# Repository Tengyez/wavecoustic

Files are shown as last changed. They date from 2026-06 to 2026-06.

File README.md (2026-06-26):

# Wavecoustic

An ESP-32 with INMP441 mic to analyse piano sound using FFT (Fast Fourier transform) to light up WS2812B led on the corresponding across the piano key.

## Description

This is a controller for a LED strip that lights up a piano key when pressed. I know a version of this had been done before; however, as far as I know, there had only been a version where the input for the LED was from MIDI, which is impossible to do with an older piano or an acoustic piano. I wanted to make this project so much because looking back I would have practiced the piano so much more if it wasn't so boring. So, my goal is to use an actual microphone input and FFT to translate the sound wave signal into individual key notes. So that it becomes fun and usable. I wanted to make this project because I have an acoustic piano but I can't use led on it because it doesn't have a midi output so this project that only use sound will be a game changer for me! Thank you!

## Getting Started

### Usage

* Place the 1.4m led strip over the piano in possition.
* Charge your external LIPO-battery using Tp4056 usb-c charging module.
* Plug the external lipo battery in and rest it on the holder (please be aware of the polarlity).
* Set the setting mode and brightness via esp32-accesspoint captive portal.

### Assembling

* Print out the 3d parts (body,slider,topper,boostcover and please use the 3mf file I beg you)
* Put the esp-32 into the main body
* Stack the esp32 cover lid over the esp32 to lock it in place
* stick all the pin header into it own slot
* follow the wiring guide below
* put the microphone into the 6 headerpin slot
* stuff all the wiring jumper wires into the case
* connect the led strip into the external headerpin
* charge the lipo with the Tp4056 module (not include in the circuit and the case)
* connect the lipo to the external header pin
* cut your 2m led strip to your piano size
* use a multimeter to check the boost converter and adjust first using a screw prior to adding it to the circuit
* take the sliding lid and close it
* mount the led and the component box on your piano
* The only point require soldering are the INMP441 mic and the GND wires. 

### Wiring
* INMP441 - ESP32
* VDD  - 3.3V
* GND  - GND
* SCK  - GPIO32
* WS   - GPIO25
* SD   - GPIO34
* L/R  - GND
* WS2812B LED STRIP
* DIN  - 300Ω → GPIO13
* GND  - GND
* MT3608 boost converter (use a multimeter to check the boost and adjust first prior to adding electricity)
* +Vout - led strip 5v pin
* -Vout - GND
* Lipo battery (preferably 20 000mah)
* Splice the red wire before connecting it to the boost converter and connect it to ESP-32 VIN pin
* Red wire   - MT3608 +Vin pin
* Black wire - GND
* Splice all GND together and add solder and a electrical tape!!!
* Refers to the schematic down below for more indepth guide.

### Firmware

* The code is in C++ made for ESP-32
* The library version might change over time, please recheck it again.
* Sidenote: I'm not really sure about the code but I tried my best to polish it because my friend quit half way :(
* Check out the [Firmware](firmware/Firmware.ino)
## Materials

This is the BOM of the entire project, just buy the normal one not the pcb version and just use jumper wire with minimal soldering required except for slicing GND together.
```
ESP-32 devkit v1           1 pcs. 8usd
INMP441 mic                1 pcs. 1usd
WS2812B led                2m 144/m 20usd
LIPO-battery               1 (reccomend atleast 10 000mah) 7usd
Tp4056 usb-c               1 (does not include in the build, only use the charge lipo externally) 1usd
MT3608 boost converter     1 pcs. 1usd
Female Jumper wires        30 pcs. 1usd
Male Jumper wires          15 pcs. 50cent
Pin headers                5 pcs. 25cent
Electrical tape            1 roll -
PLA 3d printing/time       ≈15g ≈45min -
Total: 39.75 usd
```

## Assembled Pictures


## Rendered Pictures


## Captive Portal interface


## Wiring Diagram 
SCH_Schematic1_2026-06-14 (1)_page-0001

# Zine Poster
waaavecoustic (1)

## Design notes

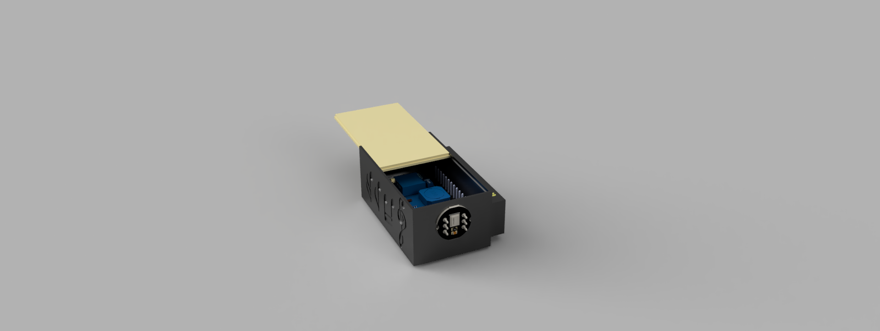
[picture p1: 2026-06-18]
docs/model_pictures/bottom_open.png

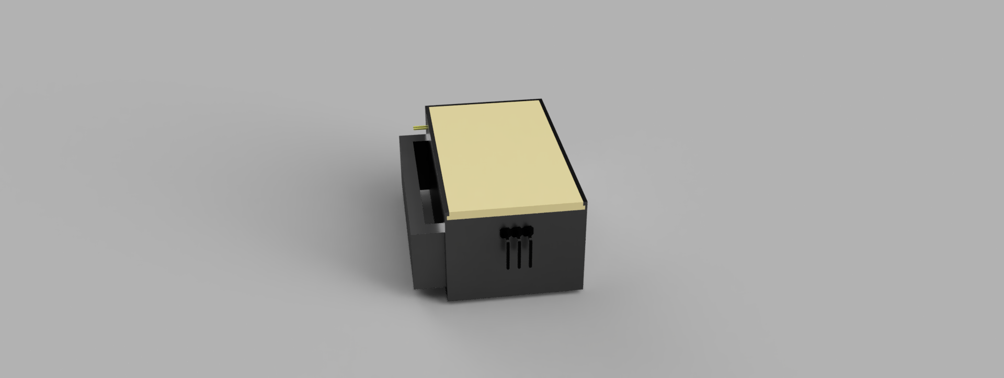
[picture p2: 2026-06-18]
docs/model_pictures/bottom_closed.png

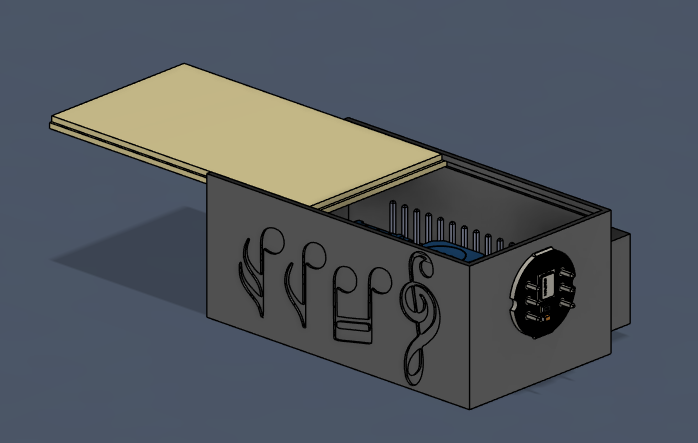
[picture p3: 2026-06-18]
docs/model_pictures/side_open.png

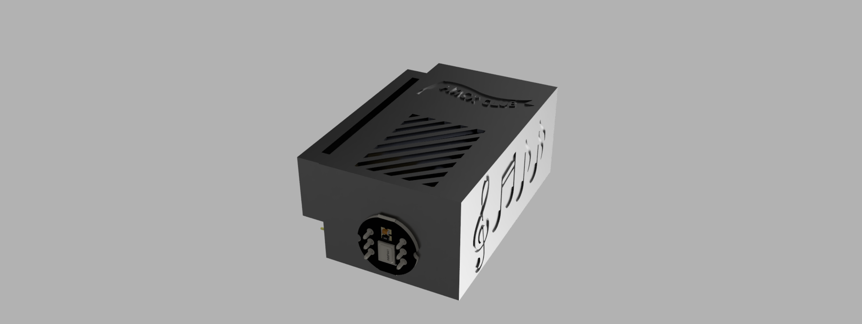
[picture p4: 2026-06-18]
docs/model_pictures/mainshot.PNG

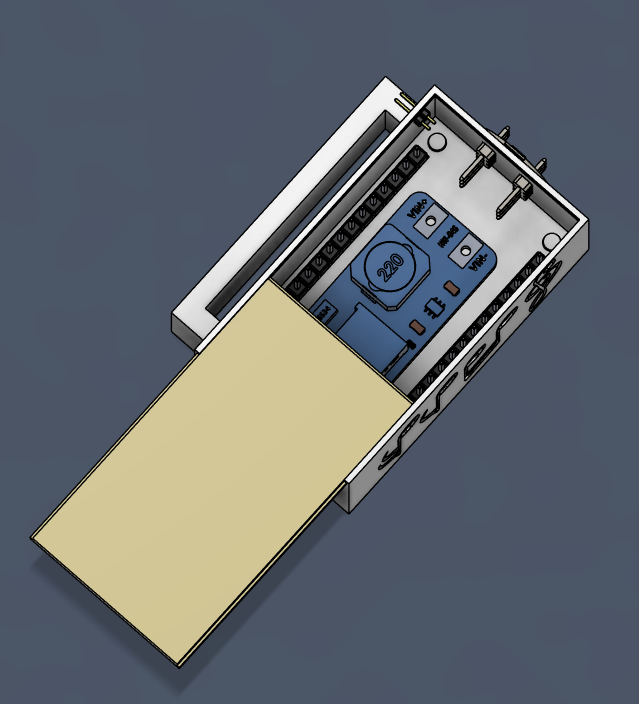
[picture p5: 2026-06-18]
docs/model_pictures/bottom_unrendered.png

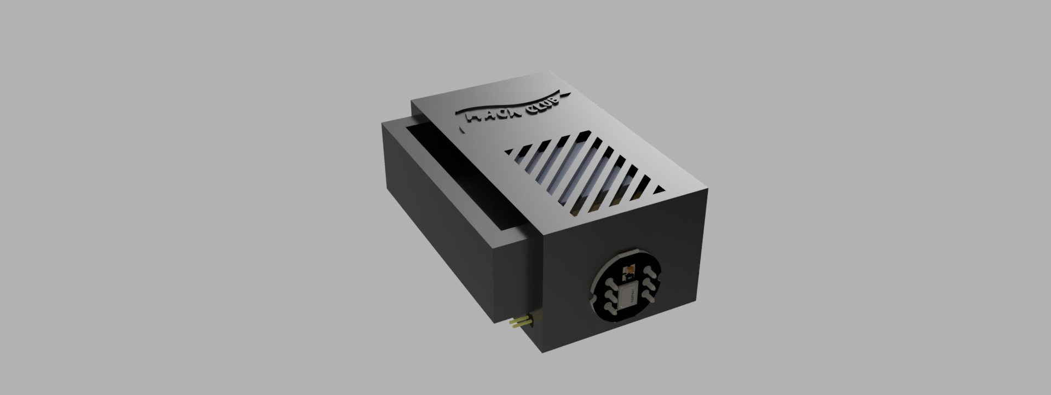
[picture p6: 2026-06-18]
docs/model_pictures/left_front.png

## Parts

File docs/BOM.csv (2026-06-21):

component | quantity | comment | link | cost
ESP-32 devkit v1 | 1pcs. | - | https://shopee.co.th/ESP32-DOIT-ESP32-DEVKIT-V1-ESP-32S-NodeMCU-ESP-WROOM-32-Wi-Fi-and-Bluetooth-Dual-Core-ESP-32-ESP-32S-ESP-32D-i.56846818.6732213287 | 8usd
INMP441 mic | 1pcs. | - | https://www.allnewstep.com/product/4864/inmp441-%E0%B9%82%E0%B8%A1%E0%B8%94%E0%B8%B9%E0%B8%A5%E0%B9%84%E0%B8%A1%E0%B9%82%E0%B8%84%E0%B8%A3%E0%B9%82%E0%B8%9F%E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 | 1usd
LIPO battery | 1pcs. | reccomended 20 000mah | https://shopee.co.th/%E0%B9%81%E0%B8%9A%E0%B8%95%E0%B9%80%E0%B8%95%E0%B8%AD%E0%B8%A3%E0%B8%B5%E0%B9%88-3.7v-20000mAh-size1260110-li-polymer-%E0%B8%A5%E0%B8%B4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 | 7usd
WS2812B led | 2m | 144/m | https://shopee.co.th/Ws2812b-WS2812-Led-Strip-%E0%B8%AA%E0%B9%88%E0%B8%A7%E0%B8%99%E0%B8%9A%E0%B8%B8%E0%B8%84%E0%B8%84%E0%B8%A5%E0%B8%97%E0%B8%B5%E0%B9%88%E0%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 | 20usd
TP4056 | 1pcs. | not include in build (charge lipo externally) | https://www.ortech-online.com/product/434/1%E0%B8%8A%E0%B8%B4%E0%B9%89%E0%B8%99-aa477-%E0%B9%82%E0%B8%A1%E0%B8%94%E0%B8%B9%E0%B8%A5%E0%B8%8A%E0%B8%B2%E0%B8%A3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 | 1usd
MT3608 | 1pcs. | - | https://www.ortech-online.com/product/199/3%E0%B8%8A%E0%B8%B4%E0%B9%89%E0%B8%99-aa180-%E0%B9%82%E0%B8%A1%E0%B8%94%E0%B8%B9%E0%B8%A5%E0%B9%80%E0%B8%9E%E0%B8%B4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 | 1usd
Female Jumper | 30pcs. | gpio | https://www.ortech-online.com/product/344/1%E0%B8%8A%E0%B8%B4%E0%B9%89%E0%B8%99-aa047-%E0%B8%AA%E0%B8%B2%E0%B8%A2%E0%B9%80%E0%B8%8A%E0%B8%B7%E0%B9%88%E0%B8%AD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 | 1usd
Male Jumper | 15pcs. | gpio | https://www.ortech-online.com/product/344/1%E0%B8%8A%E0%B8%B4%E0%B9%89%E0%B8%99-aa047-%E0%B8%AA%E0%B8%B2%E0%B8%A2%E0%B9%80%E0%B8%8A%E0%B8%B7%E0%B9%88%E0%B8%AD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 | 50cent
Pin header | 5pcs. | 2.54mm | https://www.ortech-online.com/product/917/10%E0%B8%8A%E0%B8%B4%E0%B9%89%E0%B8%99-%E0%B8%81%E0%B9%89%E0%B8%B2%E0%B8%87%E0%B8%9B%E0%B8%A5%E0%B8%B2-%E0%B8%95%E0%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 | 25cent
Electrical tape | 1pcs. | a roll for covering copper wires | any | -
PLA | 15g | 45min | any | -
total cost: | 39.75usd

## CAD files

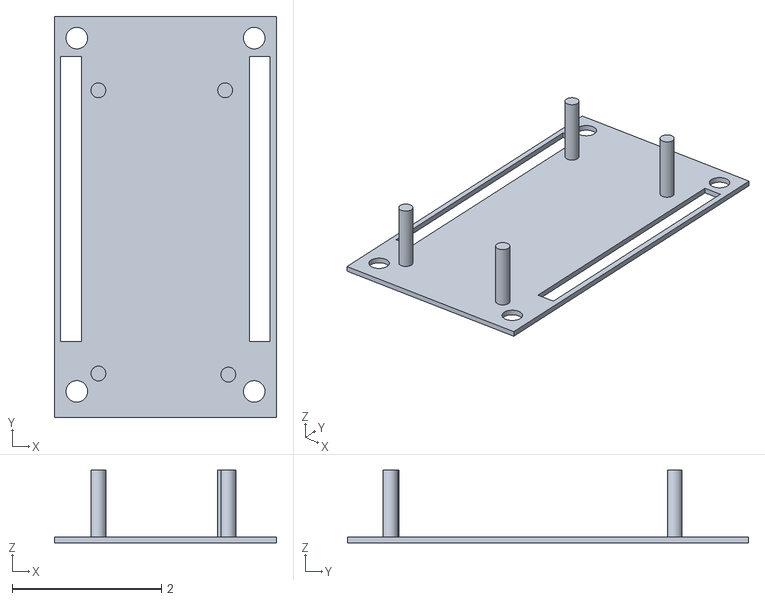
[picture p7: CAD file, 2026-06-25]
3d_print/reworked espcover.stl
2.98 x 5.38 x 0.975

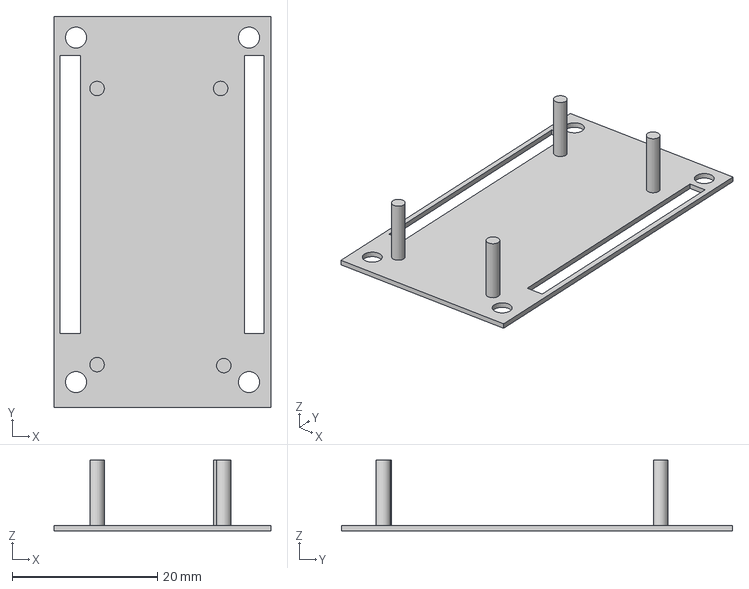
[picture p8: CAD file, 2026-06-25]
3d_print/esp32 cover rework fixing.3mf
29.8 x 53.8 x 9.75 mm

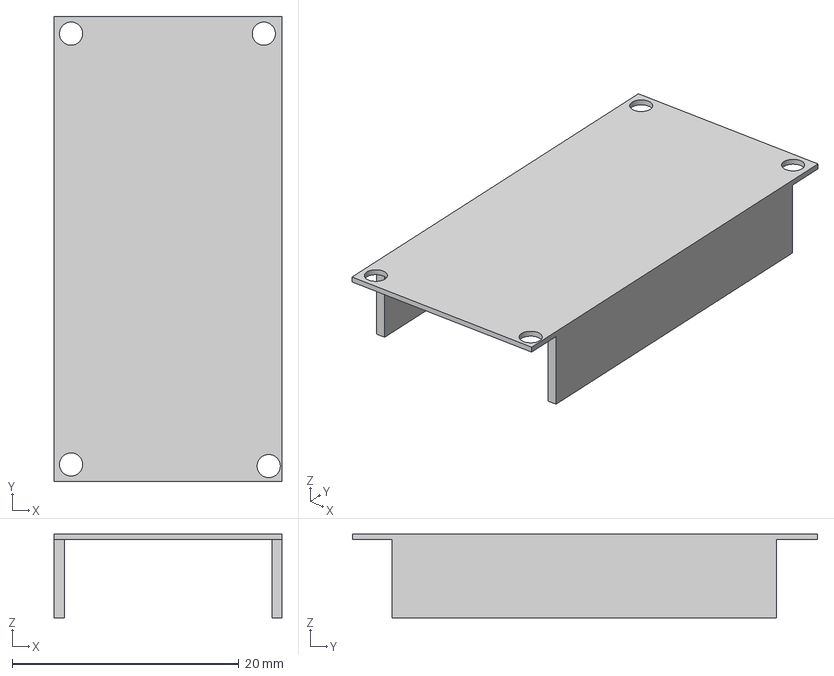
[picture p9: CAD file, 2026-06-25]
3d_print/boostcover.3mf
20.1 x 41.0 x 7.40 mm

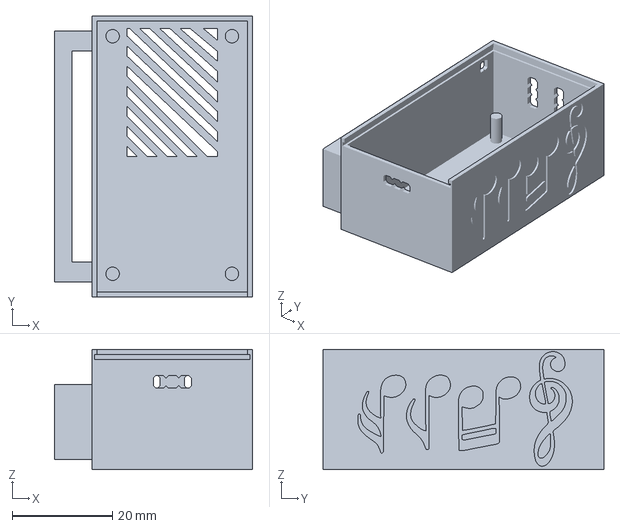
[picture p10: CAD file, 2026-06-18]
3d_print/body.3mf
39.5 x 56.0 x 24.0 mm

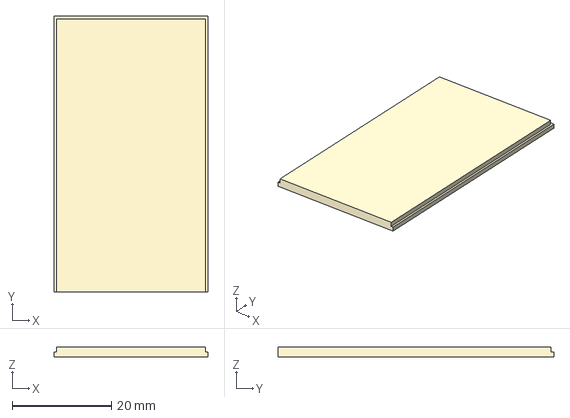
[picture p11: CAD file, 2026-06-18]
3d_print/slider.3mf
31.0 x 55.5 x 1.98 mm

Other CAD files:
3d_print/body.stl
3d_print/boostcover.stl
3d_print/slider.stl

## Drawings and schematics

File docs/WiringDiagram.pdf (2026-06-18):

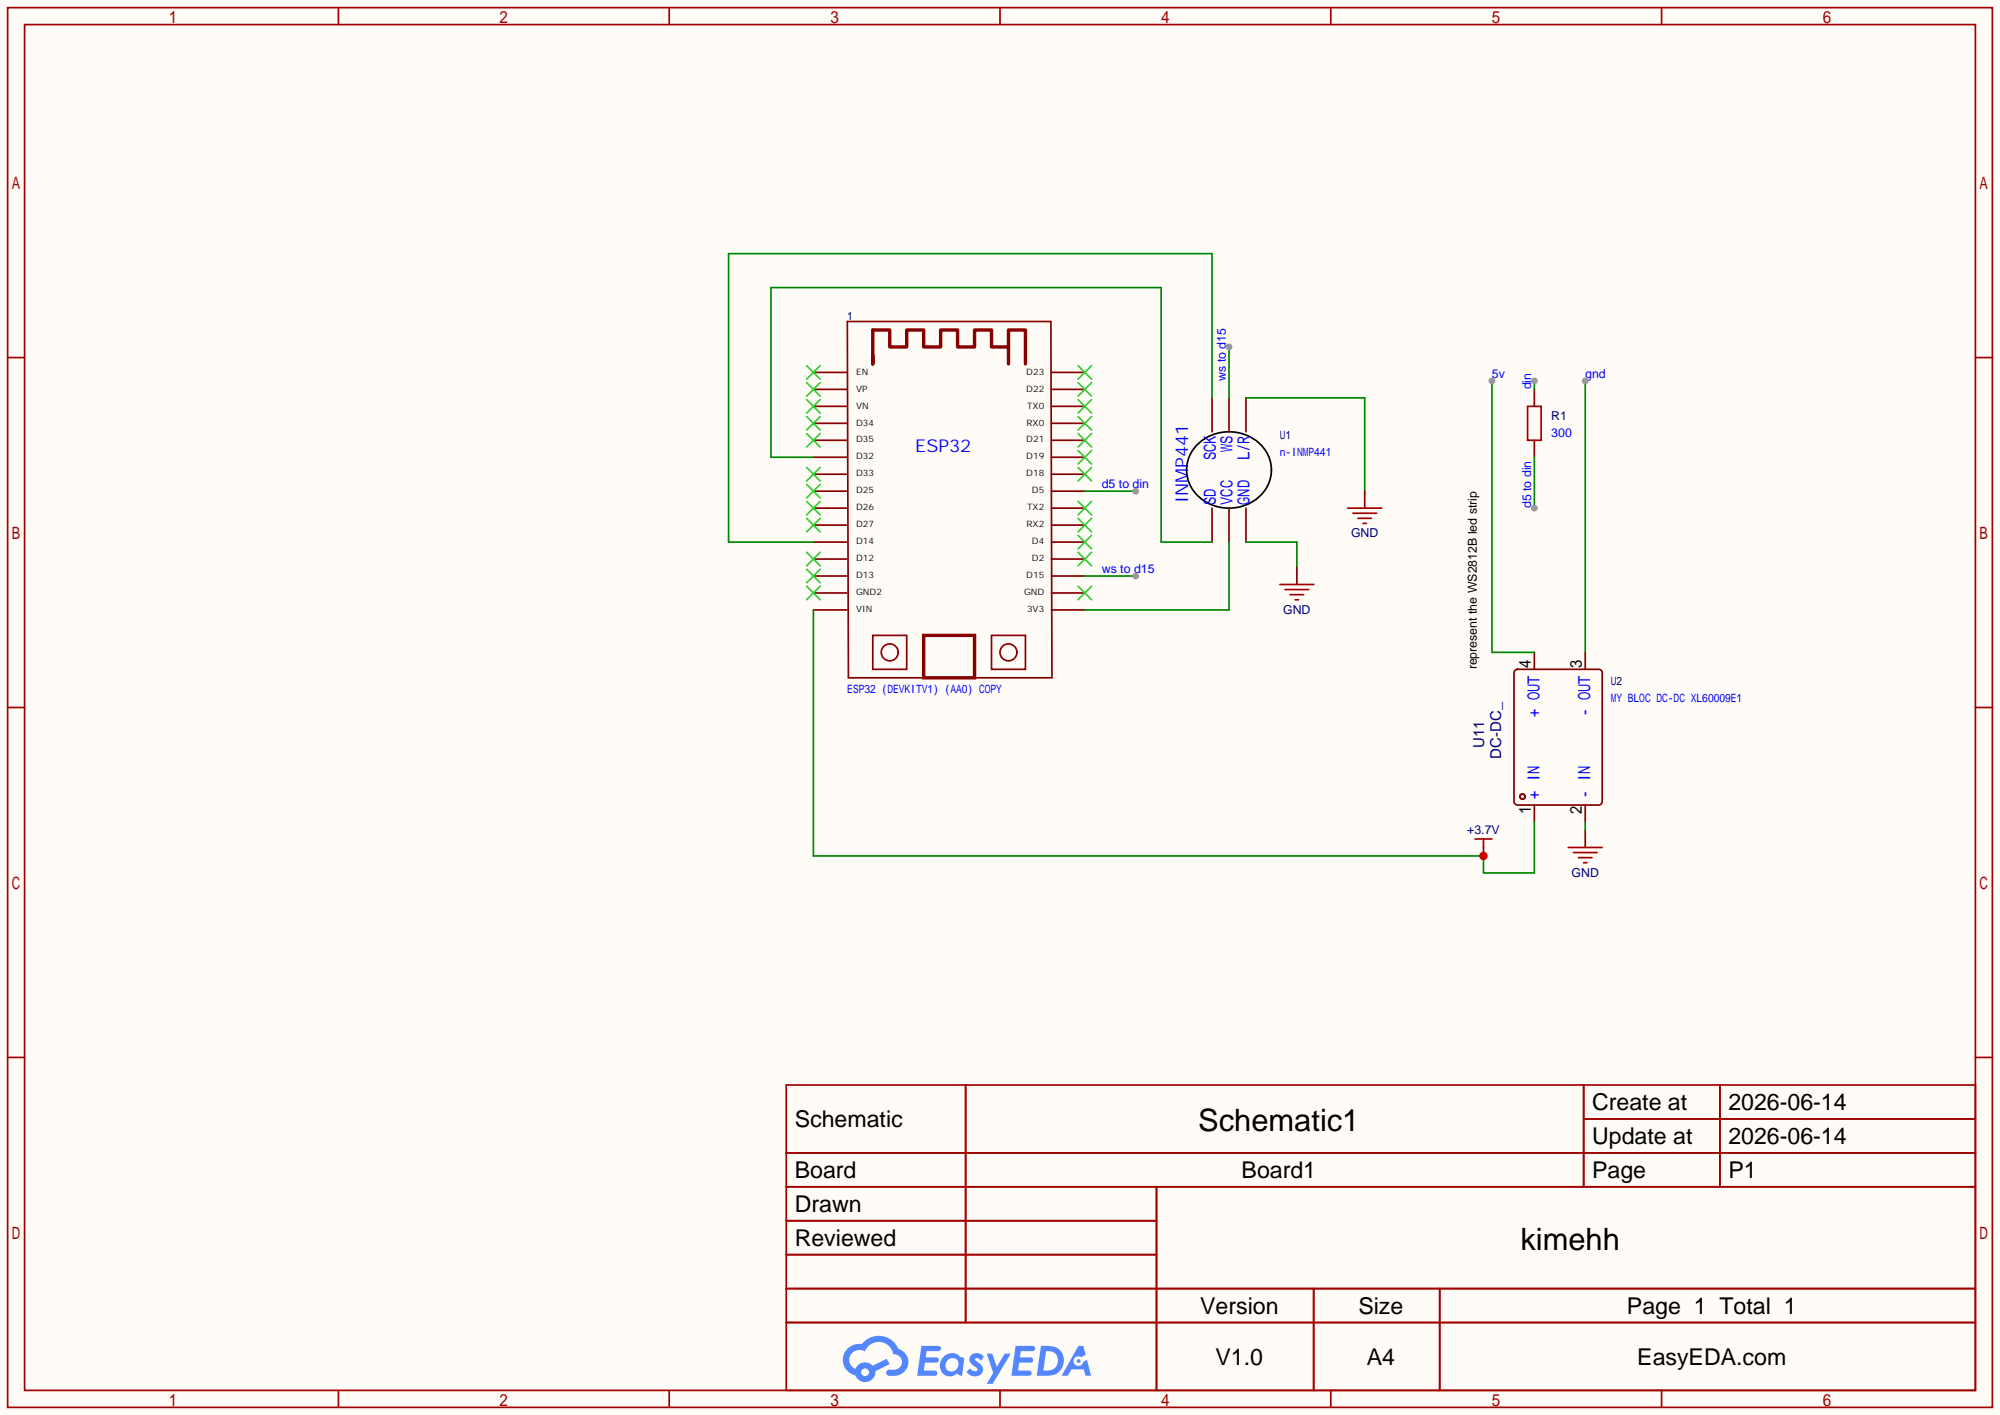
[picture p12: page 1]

represent the WS2812B led strip

MY BLOC DC-DC XL60009E1

Schematic | Schematic1 | Create at | 2026-06-14

Update at | 2026-06-14

Board | Board1 | Page | P1
Drawn | | kimehh
Reviewed

Version | Size | Page 1 Total 1
V1.0 | A4 | EasyEDA.com

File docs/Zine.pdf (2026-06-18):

## WAVE-COUSTIC

## by Teng & Kim 15y

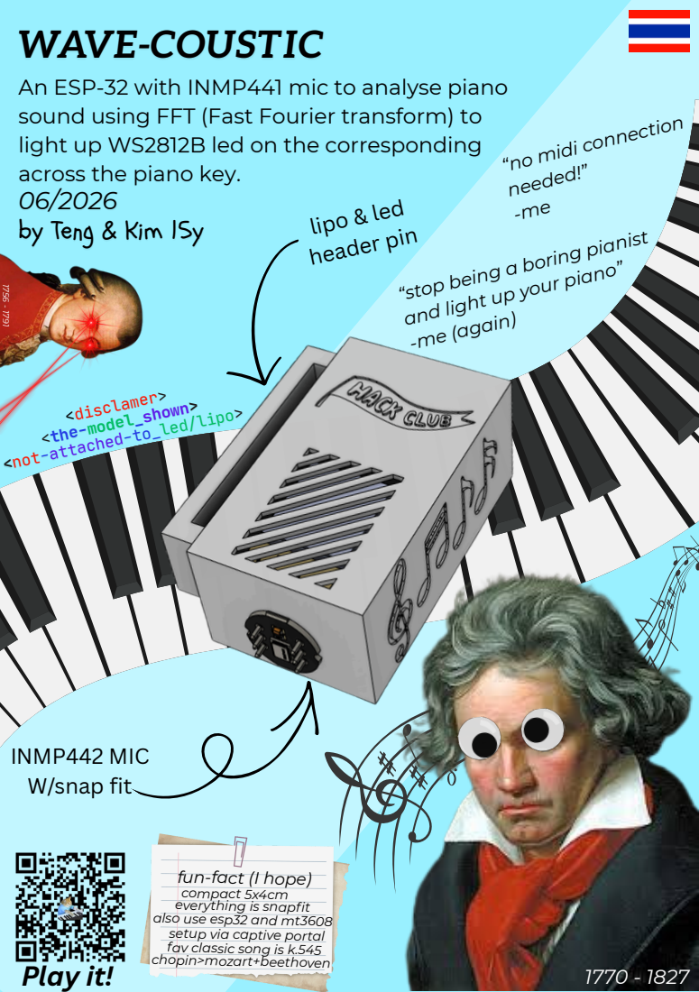
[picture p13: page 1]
needed!” -me; <disclamer> <the-model_; shown>; <not-at; s hed-to_; led/lipo>; clamer> <the-model_; shown> <not-attached-to_; Play it!; INMP442 MIC; W/snap fit; lipo & led header pin; compact 5x4cm; -me (again)

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

“no midi connection

“stop being a boring pianist

and light up your piano”

fun-fact (I hope)

everything is snapfit

also use esp32 and mt3608

setup via captive portal

fav classic song is k.545

chopin>mozart+beethoven

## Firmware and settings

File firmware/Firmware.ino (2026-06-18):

#include <Arduino.h>
#include <driver/i2s.h>
#include <arduinoFFT.h>
#include <FastLED.h>
#include <WiFi.h>
#include <ESPAsyncWebServer.h>
#include <AsyncWebSocket.h>
#include <DNSServer.h>

#define FREQ_MAX        4186.0f
#define FREQ_MIN        27.5f
#define SAMPLE          1024
#define SAMPLE_RATE     22050
#define MAG_THRESHOLD   3000

#define I2S_WS          25
#define I2S_SD          34
#define I2S_SCK         32
#define LED_PIN         13
#define JAX_ADC_PIN     35

#define NUM_KEY         88
#define LED_PER_KEY     2
#define NUM_LED         176
#define MAX_AMPS        1500
#define BRIGHTNESS      150

typedef enum { INPUT_I2S, INPUT_JAX } InputMode;
InputMode inputMode = INPUT_I2S;

typedef enum { COLOR_BY_FREQ, COLOR_RAINBOW, COLOR_WHITE } ColorMode;
ColorMode colorMode = COLOR_BY_FREQ;
uint8_t ledBrightness = BRIGHTNESS;
const char* NOTE_NAMES[NUM_KEY] = {
    "A0","A#0","B0",
    "C1","C#1","D1","D#1","E1","F1","F#1","G1","G#1","A1","A#1","B1",
    "C2","C#2","D2","D#2","E2","F2","F#2","G2","G#2","A2","A#2","B2",
    "C3","C#3","D3","D#3","E3","F3","F#3","G3","G#3","A3","A#3","B3",
    "C4","C#4","D4","D#4","E4","F4","F#4","G4","G#4","A4","A#4","B4",
    "C5","C#5","D5","D#5","E5","F5","F#5","G5","G#5","A5","A#5","B5",
    "C6","C#6","D6","D#6","E6","F6","F#6","G6","G#6","A6","A#6","B6",
    "C7","C#7","D7","D#7","E7","F7","F#7","G7","G#7","A7","A#7","B7",
    "C8"
};
CRGB leds[NUM_LED];

float vReal[SAMPLE];
float vImag[SAMPLE];
ArduinoFFT<float> FFT = ArduinoFFT<float>(vReal, vImag, SAMPLE, SAMPLE_RATE);

static int32_t i2sRaw[SAMPLE];
static char wsBuf[3072];
float noiseFloor = 3000.0f;
float peakMag    = 0.0f;
float peakFreq   = 0.0f;
const char* AP_SSID = "PianoLED";
DNSServer       dnsServer;
AsyncWebServer  server(80);
AsyncWebSocket  ws("/ws");

const char PORTAL_HTML[] PROGMEM = R"rawliteral(
<!DOCTYPE html>
<html>
<head>
<meta charset="UTF-8">
<meta name="viewport" content="width=device-width, initial-scale=1">
<title>PianoLED</title>
<style>
  *{margin:0;padding:0;box-sizing:border-box}
  body{
    background:#0a0a0f;color:#fff;
    font-family:'Segoe UI',sans-serif;
    min-height:100vh;display:flex;flex-direction:column;
    align-items:center;justify-content:center;overflow:hidden;
  }
  h1{font-size:1.4rem;letter-spacing:.3em;color:#888;text-transform:uppercase;margin-bottom:3rem}
  #note-display{
    display:flex;flex-wrap:wrap;justify-content:center;
    gap:14px;min-height:90px;align-items:center;max-width:90vw;
  }
  .note-chip{
    padding:10px 20px;border-radius:50px;
    font-size:1.3rem;font-weight:700;letter-spacing:.05em;
    transition:opacity .6s ease,transform .6s ease;
    opacity:1;transform:scale(1);white-space:nowrap;
  }
  .note-chip.fading{opacity:0;transform:scale(.85)}
  #status{margin-top:3rem;font-size:.75rem;color:#333;letter-spacing:.1em}
  .dot{
    display:inline-block;width:7px;height:7px;border-radius:50%;
    background:#333;margin-right:6px;vertical-align:middle;transition:background .3s;
  }
  .dot.live{background:#00ff88}
  #settings{
    margin-top:2rem;display:flex;gap:12px;flex-wrap:wrap;justify-content:center;
  }
  select{
    background:#111;color:#aaa;border:1px solid #333;
    border-radius:8px;padding:6px 12px;font-size:.8rem;cursor:pointer;
  }
  select:focus{outline:none;border-color:#555}
  input[type=range]{width:160px;accent-color:#00b4ff}
</style>
</head>
<body>
<h1>PianoLED</h1>
<div id="note-display">
  <span style="color:#333;font-size:.9rem;letter-spacing:.2em">LISTENING...</span>
</div>
<div id="settings">
  <select id="inputSel" onchange="sendSetting('input',this.value)">
    <option value="0">🎙 I2S Mic</option>
    <option value="1"> 3.5mm Jack</option>
  </select>
  <select id="colorSel" onchange="sendSetting('color',this.value)">
    <option value="0">By Frequency</option>
    <option value="1"> Rainbow</option>
    <option value="2"> White</option>
  </select>
  <input type="range" id="volSel" min="0" max="255" value="150" oninput="sendSetting('brightness',this.value)">
</div>
<div id="status">
  <span class="dot" id="dot"></span>
  <span id="status-text">CONNECTING</span>
</div>
<script>
  function noteColor(freq){
    if(freq<120)  return{bg:'rgba(255,30,0,.15)',  border:'#ff1e00',text:'#ff6040'};
    if(freq<250)  return{bg:'rgba(255,80,0,.15)',  border:'#ff5000',text:'#ff8040'};
    if(freq<500)  return{bg:'rgba(255,200,0,.15)', border:'#ffc800',text:'#ffd040'};
    if(freq<1000) return{bg:'rgba(0,255,80,.15)',  border:'#00ff50',text:'#40ff80'};
    if(freq<2000) return{bg:'rgba(0,180,255,.15)', border:'#00b4ff',text:'#40ccff'};
    if(freq<3000) return{bg:'rgba(0,80,255,.15)',  border:'#0050ff',text:'#4080ff'};
    return         {bg:'rgba(180,0,255,.15)',       border:'#b400ff',text:'#cc40ff'};
  }

  const display   = document.getElementById('note-display');
  const dot       = document.getElementById('dot');
  const stText    = document.getElementById('status-text');
  const activeChips = {};
  const FADE_DELAY_MS = 600;

  function showNotes(notes){
    const incoming = new Set(notes.map(n=>n.name));
    
    if(notes.length > 0 && display.querySelector('span')) {
      display.innerHTML = '';
    }

    notes.forEach(({name,freq})=>{
      if(activeChips[name]){
        clearTimeout(activeChips[name].fadeTimer);
        activeChips[name].el.classList.remove('fading');
        activeChips[name].fadeTimer=null;
      } else {
        const c=noteColor(freq);
        const chip=document.createElement('div');
        chip.className='note-chip';
        chip.textContent=name;
        chip.style.background=c.bg;
        chip.style.border=`1.5px solid ${c.border}`;
        chip.style.color=c.text;
        chip.style.boxShadow=`0 0 18px ${c.border}55`;
        display.appendChild(chip);
        activeChips[name]={el:chip,fadeTimer:null};
      }
    });

    Object.keys(activeChips).forEach(name=>{
      if(!incoming.has(name)&&!activeChips[name].fadeTimer){
        activeChips[name].el.classList.add('fading');
        activeChips[name].fadeTimer=setTimeout(()=>{
          activeChips[name].el.remove();
          delete activeChips[name];
          if(Object.keys(activeChips).length===0)
            display.innerHTML='<span style="color:#333;font-size:.9rem;letter-spacing:.2em">LISTENING...</span>';
        },FADE_DELAY_MS);
      }
    });
  }

  function sendSetting(key,val){
    if(ws&&ws.readyState===1) ws.send(JSON.stringify({[key]:parseInt(val)}));
  }

  let ws;
  function connect(){
    ws=new WebSocket('ws://'+location.hostname+'/ws');
    ws.onopen=()=>{dot.classList.add('live');stText.textContent='LIVE'};
    ws.onmessage=(e)=>{
      try{
        const data=JSON.parse(e.data);
        if(Array.isArray(data)) showNotes(data);
        if(data.input!==undefined) document.getElementById('inputSel').value=data.input;
        if(data.color!==undefined) document.getElementById('colorSel').value=data.color;
        if(data.brightness!==undefined) document.getElementById('volSel').value=data.brightness;
      }catch(err){}
    };
    ws.onclose=()=>{
      dot.classList.remove('live');
      stText.textContent='RECONNECTING...';
      setTimeout(connect,1500);
    };
  }
  connect();
</script>
</body>
</html>
)rawliteral";

void setupI2S() {
    i2s_config_t config = {
        .mode                 = (i2s_mode_t)(I2S_MODE_MASTER | I2S_MODE_RX),
        .sample_rate          = SAMPLE_RATE,
        .bits_per_sample      = I2S_BITS_PER_SAMPLE_32BIT,
        .channel_format       = I2S_CHANNEL_FMT_ONLY_LEFT,
        .communication_format = (i2s_comm_format_t)(I2S_COMM_FORMAT_STAND_I2S),
        .intr_alloc_flags     = ESP_INTR_FLAG_LEVEL1,
        .dma_buf_count        = 8,
        .dma_buf_len          = 64,
        .use_apll             = false,
        .tx_desc_auto_clear   = false,
        .fixed_mclk           = 0
    };
    i2s_pin_config_t pin_config = {
        .bck_io_num   = I2S_SCK,
        .ws_io_num    = I2S_WS,
        .data_out_num = I2S_PIN_NO_CHANGE,
        .data_in_num  = I2S_SD
    };
    i2s_driver_install(I2S_NUM_0, &config, 0, NULL);
    i2s_set_pin(I2S_NUM_0, &pin_config);
}

void calibrateNoise() {
    Serial.println("Calibrating noise floor... keep quiet for 2 seconds");
    float maxNoise = 0.0f;
    for (int pass = 0; pass < 4; pass++) {
        size_t bytesRead;
        i2s_read(I2S_NUM_0, i2sRaw, sizeof(i2sRaw), &bytesRead, portMAX_DELAY);
        int sampleCount = bytesRead / sizeof(int32_t);
        for (int i = 0; i < sampleCount && i < SAMPLE; i++) {
            vReal[i] = (float)i2sRaw[i] / 2147483648.0f;
            vImag[i] = 0.0f;
        }
        FFT.windowing(FFT_WIN_TYP_HANN, FFT_FORWARD);
        FFT.compute(FFT_FORWARD);
        FFT.complexToMagnitude();
        for (int i = 2; i < SAMPLE / 2; i++) {
            if (vReal[i] > maxNoise) maxNoise = vReal[i];
        }
        delay(500);
    }
    noiseFloor = maxNoise * 1.5f;
    Serial.printf("Noise floor set to: %.4f\n", noiseFloor);
}

void readI2S() {
    size_t bytesRead;
    i2s_read(I2S_NUM_0, i2sRaw, sizeof(i2sRaw), &bytesRead, portMAX_DELAY);
    for (int i = 0; i < SAMPLE; i++) {
        vReal[i] = (float)i2sRaw[i] / 2147483648.0f;
        vImag[i] = 0.0f;
    }
}

void readJax() {
    for (int i = 0; i < SAMPLE; i++) {
        unsigned long startUs = micros();
        int raw = analogRead(JAX_ADC_PIN);
        vReal[i] = (float)(raw - 2048) / 2048.0f;
        vImag[i] = 0.0f;
        while ((micros() - startUs) < 45) {
            
        }
    }
}

int freqToled(float freq) {
    if (freq < FREQ_MIN || freq > FREQ_MAX) return -1;
    float logMin = logf(FREQ_MIN);
    float logMax = logf(FREQ_MAX);
    float logF   = logf(freq);
    int key = (int)((logF - logMin) / (logMax - logMin) * (NUM_KEY - 1));
    return constrain(key, 0, NUM_KEY - 1);
}

bool isHarmonic(float freq, float fundamental) {
    for (int h = 2; h <= 6; h++) {
        float harmonic = fundamental * h;
        float margin   = harmonic * 0.02f;
        if (fabsf(freq - harmonic) < margin) return true;
    }
    return false;
}

CRGB freqColor(float freq, int keyIndex) {
    switch (colorMode) {
        case COLOR_BY_FREQ:
            if (freq < 120)  return CRGB(255,  30,   0);
            if (freq < 250)  return CRGB(255,  80,   0);
            if (freq < 500)  return CRGB(255, 200,   0);
            if (freq < 1000) return CRGB(  0, 255,  80);
            if (freq < 2000) return CRGB(  0, 180, 255);
            if (freq < 3000) return CRGB(  0,  80, 255);
            return               CRGB(180,   0, 255);
        case COLOR_RAINBOW:
            return CHSV((uint8_t)((keyIndex * 255) / NUM_KEY), 255, 255);
        case COLOR_WHITE:
        default:
            return CRGB::White;
    }
}

void onWsEvent(AsyncWebSocket* server, AsyncWebSocketClient* client,
               AwsEventType type, void* arg, uint8_t* data, size_t len) {
    if (type == WS_EVT_CONNECT) {
        char buf[64];
        snprintf(buf, sizeof(buf), "{\"input\":%d,\"color\":%d,\"brightness\":%d}",
                 (int)inputMode, (int)colorMode, (int)ledBrightness);
        client->text(buf);
    } else if (type == WS_EVT_DATA) {
        AwsFrameInfo* info = (AwsFrameInfo*)arg;
        if (info->final && info->index == 0 && info->len == len && info->opcode == WS_TEXT) {
            String msg = String((char*)data).substring(0, len);
            int inputVal = -1, colorVal = -1, brightnessVal = -1;
            int idx = msg.indexOf("\"input\":");
            if (idx >= 0) inputVal = msg.substring(idx + 8).toInt();
            idx = msg.indexOf("\"color\":");
            if (idx >= 0) colorVal = msg.substring(idx + 8).toInt();
            idx = msg.indexOf("\"brightness\":");
            if (idx >= 0) brightnessVal = msg.substring(idx + 13).toInt();
            if (inputVal >= 0 && inputVal <= 1) inputMode = (InputMode)inputVal;
            if (colorVal >= 0 && colorVal <= 2) colorMode = (ColorMode)colorVal;
            if (brightnessVal >= 0 && brightnessVal <= 255) {
                ledBrightness = (uint8_t)brightnessVal;
                FastLED.setBrightness(ledBrightness);
            }
            char buf[64];
            snprintf(buf, sizeof(buf), "{\"input\":%d,\"color\":%d,\"brightness\":%d}",
                     (int)inputMode, (int)colorMode, (int)ledBrightness);
            server->textAll(buf);
        }
    }
}

void setupPortal() {
    WiFi.softAP(AP_SSID);
    IPAddress ip = WiFi.softAPIP();
    dnsServer.start(53, "*", ip);
    ws.onEvent(onWsEvent);
    server.addHandler(&ws);
    server.onNotFound([](AsyncWebServerRequest* req) {
        if (req->host() != WiFi.softAPIP().toString()) {
            req->redirect("http://" + WiFi.softAPIP().toString());
        } else {
            req->send_P(200, "text/html", PORTAL_HTML);
        }
    });
    server.begin();
    Serial.printf("Portal up at: http://%s\n", ip.toString().c_str());
}

void broadcastNotes() {
    if (ws.count() == 0) return;
    if (peakMag <= noiseFloor || peakMag <= MAG_THRESHOLD) {
        ws.textAll("[]");
        return;
    }
    float freqResolution = (float)SAMPLE_RATE / SAMPLE;

    int  pos   = 0;
    bool first = true;
    wsBuf[pos++] = '[';
    for (int i = 2; i < SAMPLE / 2; i++) {
        float freq = i * freqResolution;
        if (freq < FREQ_MIN || freq > FREQ_MAX) continue;
        float mag = vReal[i];
        if (mag < noiseFloor)           continue;
        if (mag < peakMag * 0.2f)       continue;
        if (isHarmonic(freq, peakFreq)) continue;
        int kidx = freqToled(freq);
        if (kidx < 0) continue;
        
        if (pos >= (int)sizeof(wsBuf) - 64) break;

        int written = snprintf(wsBuf + pos, sizeof(wsBuf) - pos - 2,
                               "%s{\"name\":\"%s\",\"freq\":%.1f}",
                               first ? "" : ",",
                               NOTE_NAMES[kidx],
                               freq);
        if (written > 0 && pos + written < (int)sizeof(wsBuf) - 2) {
            pos  += written;
            first = false;
        }
    }
    wsBuf[pos++] = ']';
    wsBuf[pos]   = '\0';
    ws.textAll(wsBuf);
}

void setup() {
    Serial.begin(115200);
    FastLED.addLeds<WS2812B, LED_PIN, GRB>(leds, NUM_LED);
    FastLED.setBrightness(BRIGHTNESS);
    FastLED.setMaxPowerInVoltsAndAmps(5, MAX_AMPS);
    setupI2S();
    pinMode(JAX_ADC_PIN, INPUT);
    analogReadResolution(12);
    analogSetAttenuation(ADC_ATTEN_DB_11);
    calibrateNoise();
    setupPortal();
    Serial.println("Piano LED ready");
}

void loop() {
    dnsServer.processNextRequest();
    if (inputMode == INPUT_I2S) {
        readI2S();
    } else {
        readJax();
    }
    FFT.windowing(FFT_WIN_TYP_HANN, FFT_FORWARD);
    FFT.compute(FFT_FORWARD);
    FFT.complexToMagnitude();
    peakMag  = 0.0f;
    peakFreq = 0.0f;
    float freqResolution = (float)SAMPLE_RATE / SAMPLE;
    for (int i = 2; i < SAMPLE / 2; i++) {
        float freq = i * freqResolution;
        if (freq < FREQ_MIN || freq > FREQ_MAX) continue;
        if (vReal[i] > peakMag) {
            peakMag  = vReal[i];
            peakFreq = freq;
        }
    }
    if (peakMag <= noiseFloor) {
        fadeToBlackBy(leds, NUM_LED, 20);
        FastLED.show();
        broadcastNotes();
        return;
    }
    FastLED.clear();
    if (peakMag > MAG_THRESHOLD && peakFreq > 0.0f) {
        for (int i = 2; i < SAMPLE / 2; i++) {
            float freq = i * freqResolution;
            if (freq < FREQ_MIN || freq > FREQ_MAX) continue;
            float mag = vReal[i];
            if (mag < peakMag * 0.2f)       continue;
            if (isHarmonic(freq, peakFreq)) continue;
            int kidx = freqToled(freq);
            if (kidx < 0) continue;
            int led0 = kidx * LED_PER_KEY;
            int led1 = led0 + 1;
            uint8_t bright = (uint8_t)constrain((mag / peakMag) * 255.0f, 0.0f, 255.0f);
            CRGB color = freqColor(freq, kidx);
            color.nscale8(bright);
            if (color.getLuma() > leds[led0].getLuma()) {
                leds[led0] = color;
                if (led1 < NUM_LED) leds[led1] = color;
            }
        }
    }
    broadcastNotes();
    Serial.printf("Peak: %.1f Hz  Magnitude: %.4f  Threshold: %.4f\n",
                  peakFreq, peakMag, noiseFloor);
    FastLED.show();
}

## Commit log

2026-06-17 Revise usage instructions in README
    Updated usage instructions for the device, including LED strip placement and battery charging.
2026-06-17 Add assembled and rendered pictures sections to README
2026-06-17 Update README to remove PCB pictures and add Captive Portal
    Removed PCB pictures section and added Captive Portal interface section with an image.
2026-06-17 Include Arduino code and setup details in README
    Added Arduino code and setup instructions for PianoLED project.
2026-06-18 Update README with assembled pictures section
    Added assembled pictures section with an image.
2026-06-18 Revise assembly instructions and BOM description
    Removed some assembly instructions and updated the BOM description for clarity.
2026-06-18 Add note to print out 3D parts in README
    Added note to print out the 3D parts in the assembling section.
2026-06-18 Update README with project materials list
    Added list of materials required for the project.
2026-06-18 Revise materials list in README.md
    Updated the materials list with quantities and additional details.
2026-06-18 Fix capitalization in README assembly instructions
2026-06-18 Update README with assembly and wiring details
    Added detailed assembly and wiring instructions for the project.
2026-06-18 Update README with schematic reference for wiring
    Added a reference to the schematic for wiring guidance.
2026-06-18 Revise BOM details and item quantities in README
    Updated the BOM with item quantities and additional details.
2026-06-18 Update README with soldering details
    Added soldering instructions for INMP441 mic and GND wires.
2026-06-18 Add instruction to cut LED strip to piano size
2026-06-18 Rename SCH_Schematic1_2026-06-14 (1).pdf to Schematic.pdf
2026-06-18 Rename 3MF esp32 fitcover.3mf to topper.3mf
    [topper.3mf]
2026-06-18 Revise 3D parts names in README assembly section
    Updated the 3D parts list in the assembly instructions.
2026-06-18 Rename stl small esp32 cover.stl to topper.stl
    [topper.stl]
2026-06-18 Create README with wiring instructions for firmware
    Added wiring instructions for INMP441, WS2812B LED strip, and MT3608 boost converter.
2026-06-18 Rename bomcsk - Sheet1.csv to BOM.csv
    [BOM.csv]
2026-06-21 Add firmware link and materials section to README
    Updated README to include a link to the firmware and added materials section.
2026-06-21 Add prices to materials list in README
    Updated the materials list with prices for each item.
2026-06-21 Rename Untitled spreadsheet - BOM.csv to BOM.csv
    [BOM.csv]
2026-06-21 Update BOM with additional components and costs
    [BOM.csv]
2026-06-25 Rename boost cover rework .3mf to boostcover.3mf
    [boostcover.3mf]
2026-06-25 Rename boost cover reworked.stl to boostcover.stl
    [boostcover.stl]
2026-06-25 Rename esp32 cover rework fixing.3mf to topper.3mf
    [topper.3mf]
2026-06-25 Rename reworked espcover.stl to topper.stl
    [topper.stl]
2026-06-26 Enhance README with project motivation and details
    Expanded project description to include motivation and use case for acoustic pianos.
2026-06-26 Rename 'Schematic' section to 'Wiring Diagram'
